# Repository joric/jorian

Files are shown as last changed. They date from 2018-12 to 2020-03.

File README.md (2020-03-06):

# Jorian

44-key 16-column wireless split keyboard in a 100x100 mm PCB

## Disclaimer

The keyboard layout is derived from [Jian layout](http://www.keyboard-layout-editor.com/#/gists/4b6c2af67148f58ddd6c6b2976c4370f) (just visually, there was no actual copying involved).
There are multiple [issues](https://github.com/joric/jorian/wiki/Issues) in my version.
Please buy Jian from its author, [/u/KgOfHedgehogs](http://reddit.com/u/KgOfHedgehogs), he's running a high quality commercial batch.

## Download

You can download Gerber files and schematic in the [releases section](https://github.com/joric/jorian/releases).

## Instructions

Please refer to the public [Jorian wiki](https://github.com/joric/jorian/wiki).

## Pictures

### Version 1.0

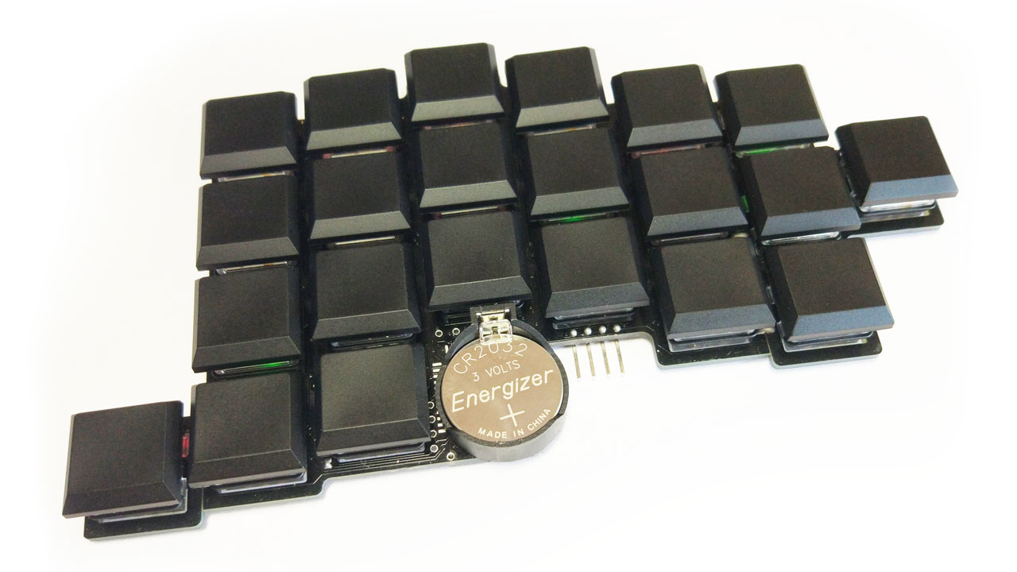
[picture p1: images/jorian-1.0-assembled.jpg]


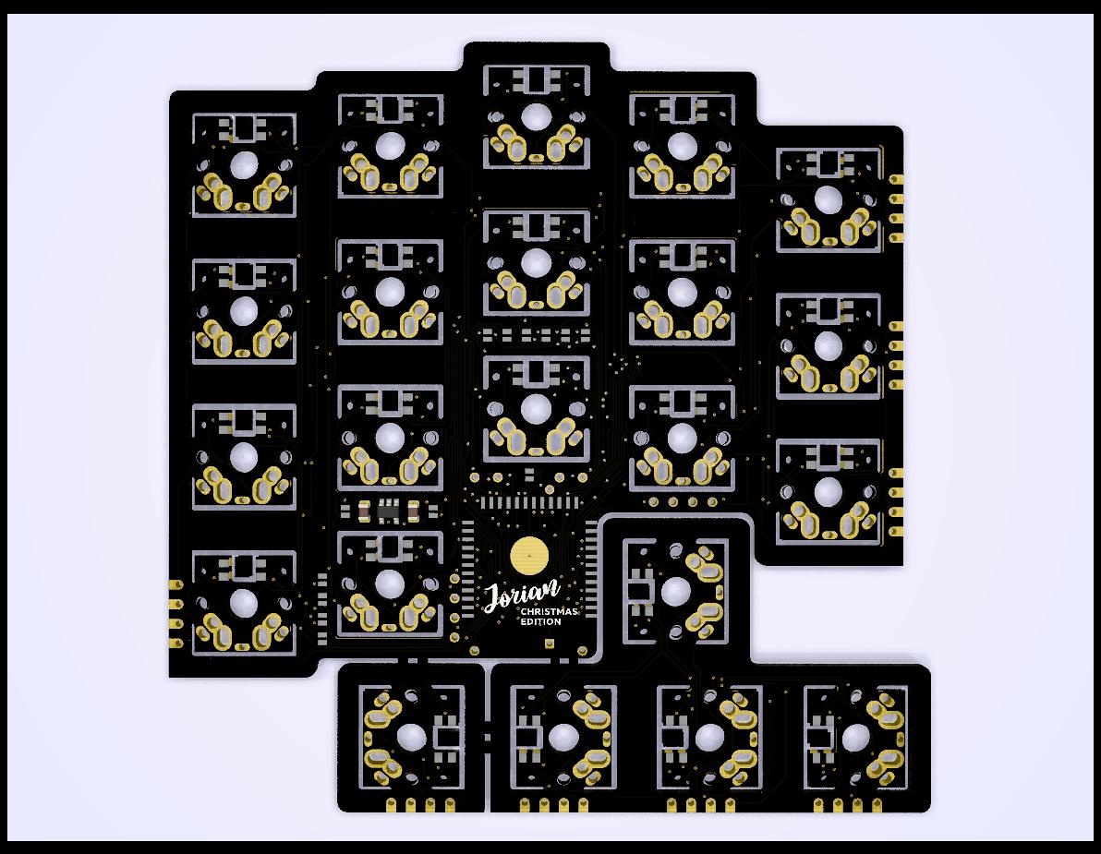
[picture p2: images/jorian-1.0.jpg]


## References

* Reddit thread: https://www.reddit.com/r/MechanicalKeyboards/comments/aj0mos/jorian_christmas_edition
* My nRF5x QMK fork: https://github.com/joric/qmk_firmware/commits/nrf52

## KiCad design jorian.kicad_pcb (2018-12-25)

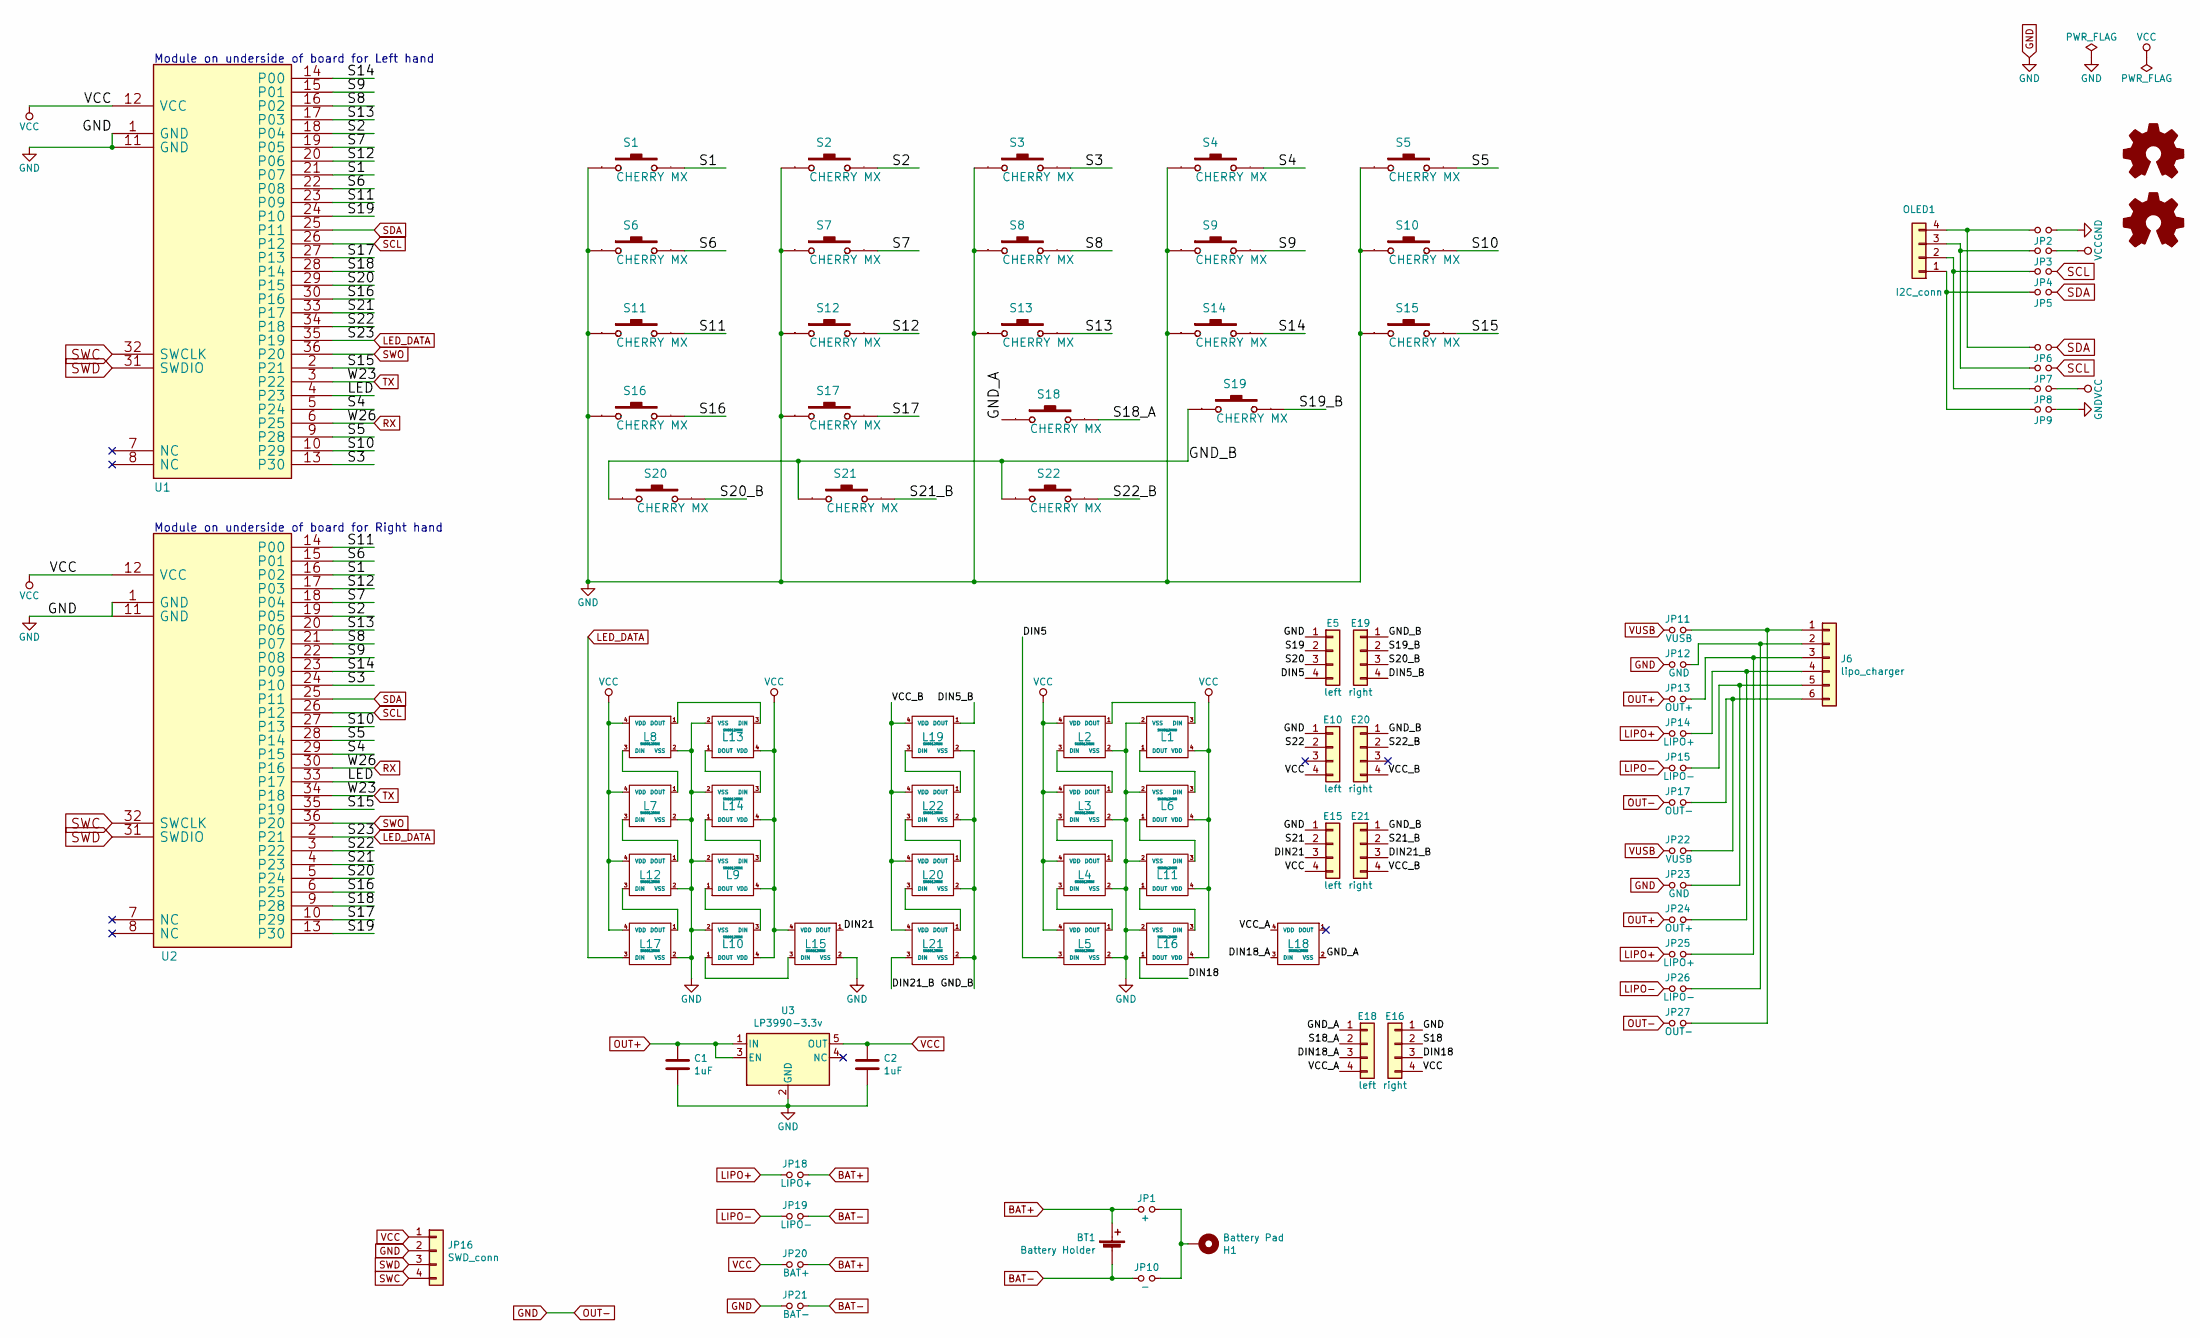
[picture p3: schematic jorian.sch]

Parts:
BT1: Battery Holder; cr2032_bs-7
C1, C2: 1uF; C_0805
E5, E10, E15, E18: left; edge_conn
E16, E19, E20, E21: right; edge_conn
G1, G2: Logo_Open_Hardware_Small; jorian_logo
H1: Battery Pad; battery_pad
J6: lipo_charger; lipo_charger_03962A
JP1: +; jumper
JP2, JP3, JP4, JP5, JP6, JP7, JP8, JP9: jumper
JP10: -; jumper
JP11, JP22: VUSB; jumper
JP12, JP23: GND; jumper
JP13, JP24: OUT+; jumper
JP14, JP18, JP25: LIPO+; jumper
JP15, JP19, JP26: LIPO-; jumper
JP16: SWD_conn; connector_swd
JP17, JP27: OUT-; jumper
JP20: BAT+; jumper
JP21: BAT-; jumper
L1, L2, L3, L4, L5, L6, L7, L8, L9, L10, L11, L12, L13, L14, L15, L16, L17, L18, L19, L20, L21, L22: SK6812MINI; kbd_SK6812MINI
OLED1: I2C_conn; connector_i2c
S1, S2, S3, S4, S5, S6, S7, S8, S9, S10, S11, S12, S13, S14, S15, S16, S17, S18, S19, S20, S21, S22: CHERRY MX; cherry
U1, U2: nrf51822_smd
U3: LP3990-3.3v; SOT-23-5

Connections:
/DIN5: E5.4, L5.3 (DIN)
/DIN5_B: E19.4, L19.1 (DOUT)
/DIN18: E16.3, L16.1 (DOUT)
/DIN18_A: E18.3, L18.3 (DIN)
/DIN21: E15.3, L15.1 (DOUT)
/DIN21_B: E21.3, L21.3 (DIN)
/GND_A: E18.1, L18.2 (VSS), S18.1
/GND_B: E19.1, E20.1, E21.1, L19.2 (VSS), L20.2 (VSS), L21.2 (VSS), L22.2 (VSS), S19.1, S20.1, S21.1, S22.1
/LED: U1.4 (P23), U2.33 (P17)
/S1: S1.2, U1.21 (P07), U2.16 (P02)
/S2: S2.2, U1.18 (P04), U2.19 (P05)
/S3: S3.2, U1.13 (P30), U2.24 (P10)
/S4: S4.2, U1.5 (P24), U2.29 (P15)
/S5: S5.2, U1.9 (P28), U2.28 (P14)
/S6: S6.2, U1.22 (P08), U2.15 (P01)
/S7: S7.2, U1.19 (P05), U2.18 (P04)
/S8: S8.2, U1.16 (P02), U2.21 (P07)
/S9: S9.2, U1.15 (P01), U2.22 (P08)
/S10: S10.2, U1.10 (P29), U2.27 (P13)
/S11: S11.2, U1.23 (P09), U2.14 (P00)
/S12: S12.2, U1.20 (P06), U2.17 (P03)
/S13: S13.2, U1.17 (P03), U2.20 (P06)
/S14: S14.2, U1.14 (P00), U2.23 (P09)
/S15: S15.2, U1.2 (P21), U2.35 (P19)
/S16: S16.2, U1.30 (P16), U2.6 (P25)
/S17: S17.2, U1.27 (P13), U2.10 (P29)
/S18: E16.2, U1.28 (P14), U2.9 (P28)
/S18_A: E18.2, S18.2
/S19: E5.2, U1.24 (P10), U2.13 (P30)
/S19_B: E19.2, S19.2
/S20: E5.3, U1.29 (P15), U2.5 (P24)
/S20_B: E19.3, S20.2
/S21: E15.2, U1.33 (P17), U2.4 (P23)
/S21_B: E21.2, S21.2
/S22: E10.2, U1.34 (P18), U2.3 (P22)
/S22_B: E20.2, S22.2
/VCC_A: E18.4, L18.4 (VDD)
/VCC_B: E20.4, E21.4, L19.4 (VDD), L20.4 (VDD), L21.4 (VDD), L22.4 (VDD)
BAT+: BT1.1 (+), JP1.2, JP18.2, JP20.2
BAT-: BT1.2 (-), JP10.2, JP19.2, JP21.2
GND: C1.2, C2.2, E5.1, E10.1, E15.1, E16.1, JP2.1, JP9.1, JP12.1, JP16.2, JP17.1, JP21.1, JP23.1, JP27.1, L1.2 (VSS), L2.2 (VSS), L3.2 (VSS), L4.2 (VSS), L5.2 (VSS), L6.2 (VSS), L7.2 (VSS), L8.2 (VSS), L9.2 (VSS), L10.2 (VSS), L11.2 (VSS), L12.2 (VSS), L13.2 (VSS), L14.2 (VSS), L15.2 (VSS), L16.2 (VSS), L17.2 (VSS), S1.1, S2.1, S3.1, S4.1, S5.1, S6.1, S7.1, S8.1, S9.1, S10.1, S11.1, S12.1, S13.1, S14.1, S15.1, S16.1, S17.1, U1.1 (GND), U1.11 (GND), U2.1 (GND), U2.11 (GND), U3.2 (GND)
LED_DATA: L17.3 (DIN), U1.35 (P19), U2.2 (P21)
LIPO+: JP14.1, JP18.1, JP25.1
LIPO-: JP15.1, JP19.1, JP26.1
unnamed: H1.1, JP1.1, JP10.1
unnamed: J6.1, JP11.2, JP27.2
unnamed: J6.2, JP12.2, JP26.2
unnamed: J6.3, JP13.2, JP25.2
unnamed: J6.4, JP14.2, JP24.2
unnamed: J6.5, JP15.2, JP23.2
unnamed: J6.6, JP17.2, JP22.2
unnamed: JP2.2, JP6.2, OLED1.4
unnamed: JP3.2, JP7.2, OLED1.3
unnamed: JP4.2, JP8.2, OLED1.2
unnamed: JP5.2, JP9.2, OLED1.1
unnamed: L1.1 (DOUT), L6.3 (DIN)
unnamed: L1.3 (DIN), L2.1 (DOUT)
unnamed: L2.3 (DIN), L3.1 (DOUT)
unnamed: L3.3 (DIN), L4.1 (DOUT)
unnamed: L4.3 (DIN), L5.1 (DOUT)
unnamed: L7.1 (DOUT), L8.3 (DIN)
unnamed: L10.1 (DOUT), L15.3 (DIN)
unnamed: L9.1 (DOUT), L10.3 (DIN)
unnamed: L11.1 (DOUT), L16.3 (DIN)
unnamed: L6.1 (DOUT), L11.3 (DIN)
unnamed: L7.3 (DIN), L12.1 (DOUT)
unnamed: L12.3 (DIN), L17.1 (DOUT)
unnamed: L13.1 (DOUT), L14.3 (DIN)
unnamed: L8.1 (DOUT), L13.3 (DIN)
unnamed: L9.3 (DIN), L14.1 (DOUT)
unnamed: L19.3 (DIN), L22.1 (DOUT)
unnamed: L20.1 (DOUT), L22.3 (DIN)
unnamed: L20.3 (DIN), L21.1 (DOUT)
OUT+: C1.1, JP13.1, JP24.1, U3.1 (IN), U3.3 (EN)
RX: U1.6 (P25), U2.30 (P16)
SCL: JP4.1, JP7.1, U1.26 (P12), U2.26 (P12)
SDA: JP5.1, JP6.1, U1.25 (P11), U2.25 (P11)
SWC: JP16.4, U1.32 (SWCLK), U2.32 (SWCLK)
SWD: JP16.3, U1.31 (SWDIO), U2.31 (SWDIO)
SWO: U1.36 (P20), U2.36 (P20)
TX: U1.3 (P22), U2.34 (P18)
VCC: C2.1, E10.4, E15.4, E16.4, JP3.1, JP8.1, JP16.1, JP20.1, L1.4 (VDD), L2.4 (VDD), L3.4 (VDD), L4.4 (VDD), L5.4 (VDD), L6.4 (VDD), L7.4 (VDD), L8.4 (VDD), L9.4 (VDD), L10.4 (VDD), L11.4 (VDD), L12.4 (VDD), L13.4 (VDD), L14.4 (VDD), L15.4 (VDD), L16.4 (VDD), L17.4 (VDD), U1.12 (VCC), U2.12 (VCC), U3.5 (OUT)
VUSB: JP11.1, JP22.1

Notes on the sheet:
Module on underside of board for Right hand
Module on underside of board for Left hand

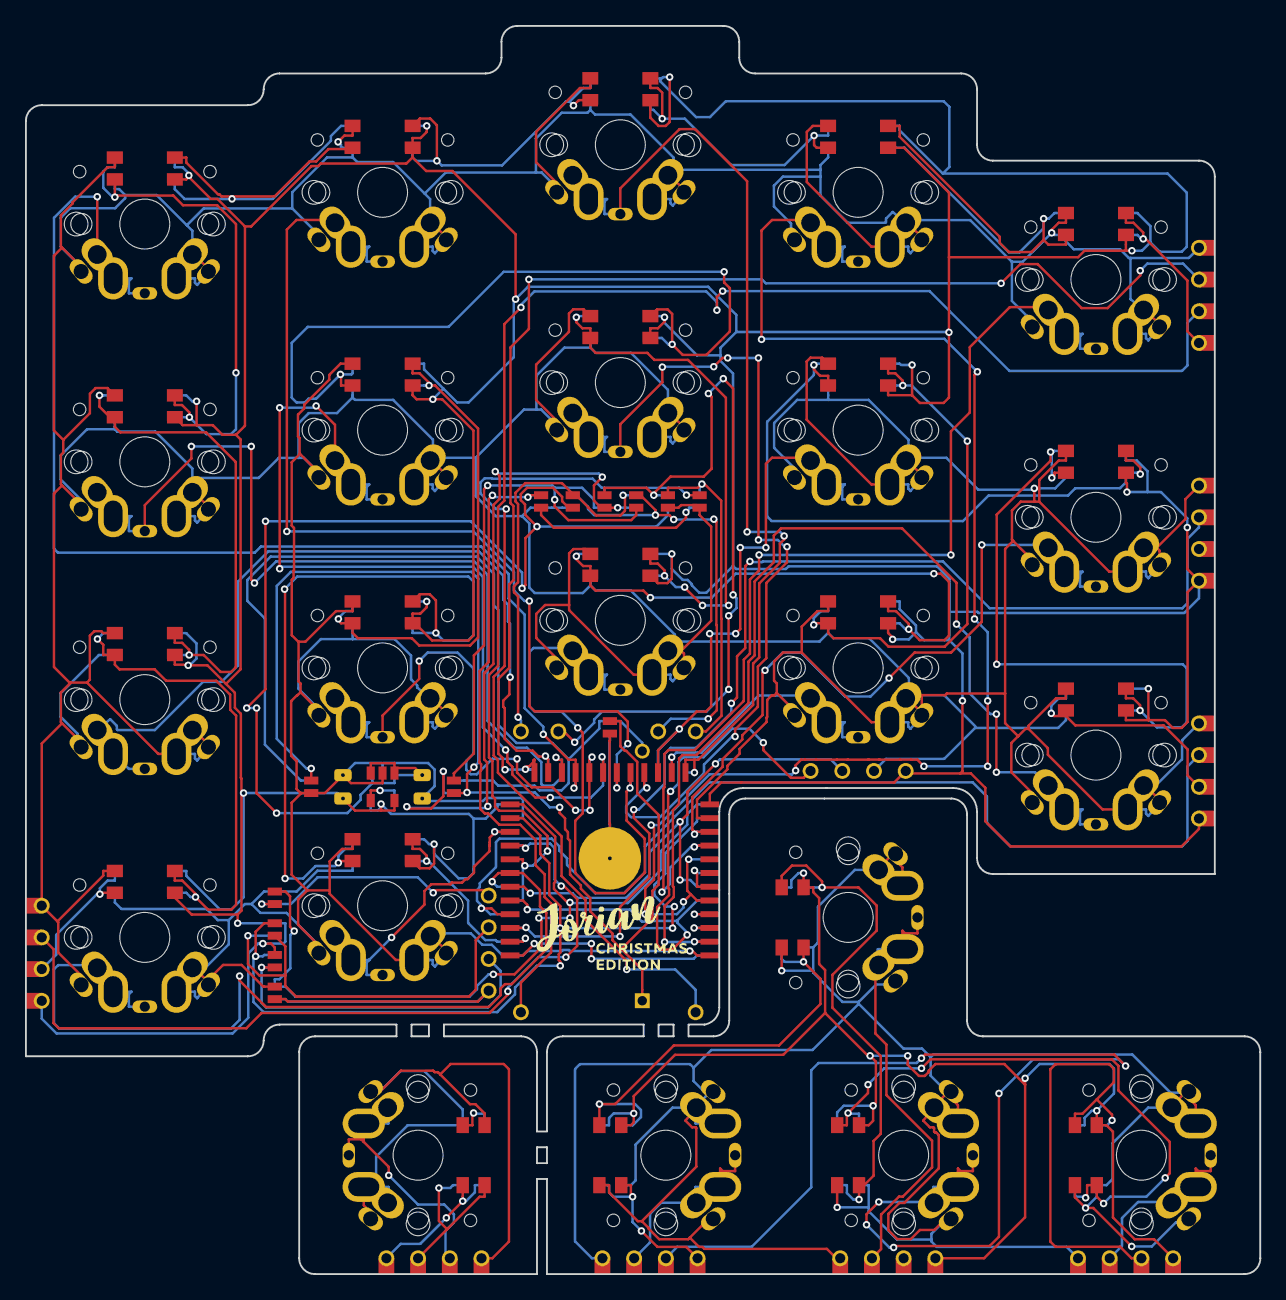
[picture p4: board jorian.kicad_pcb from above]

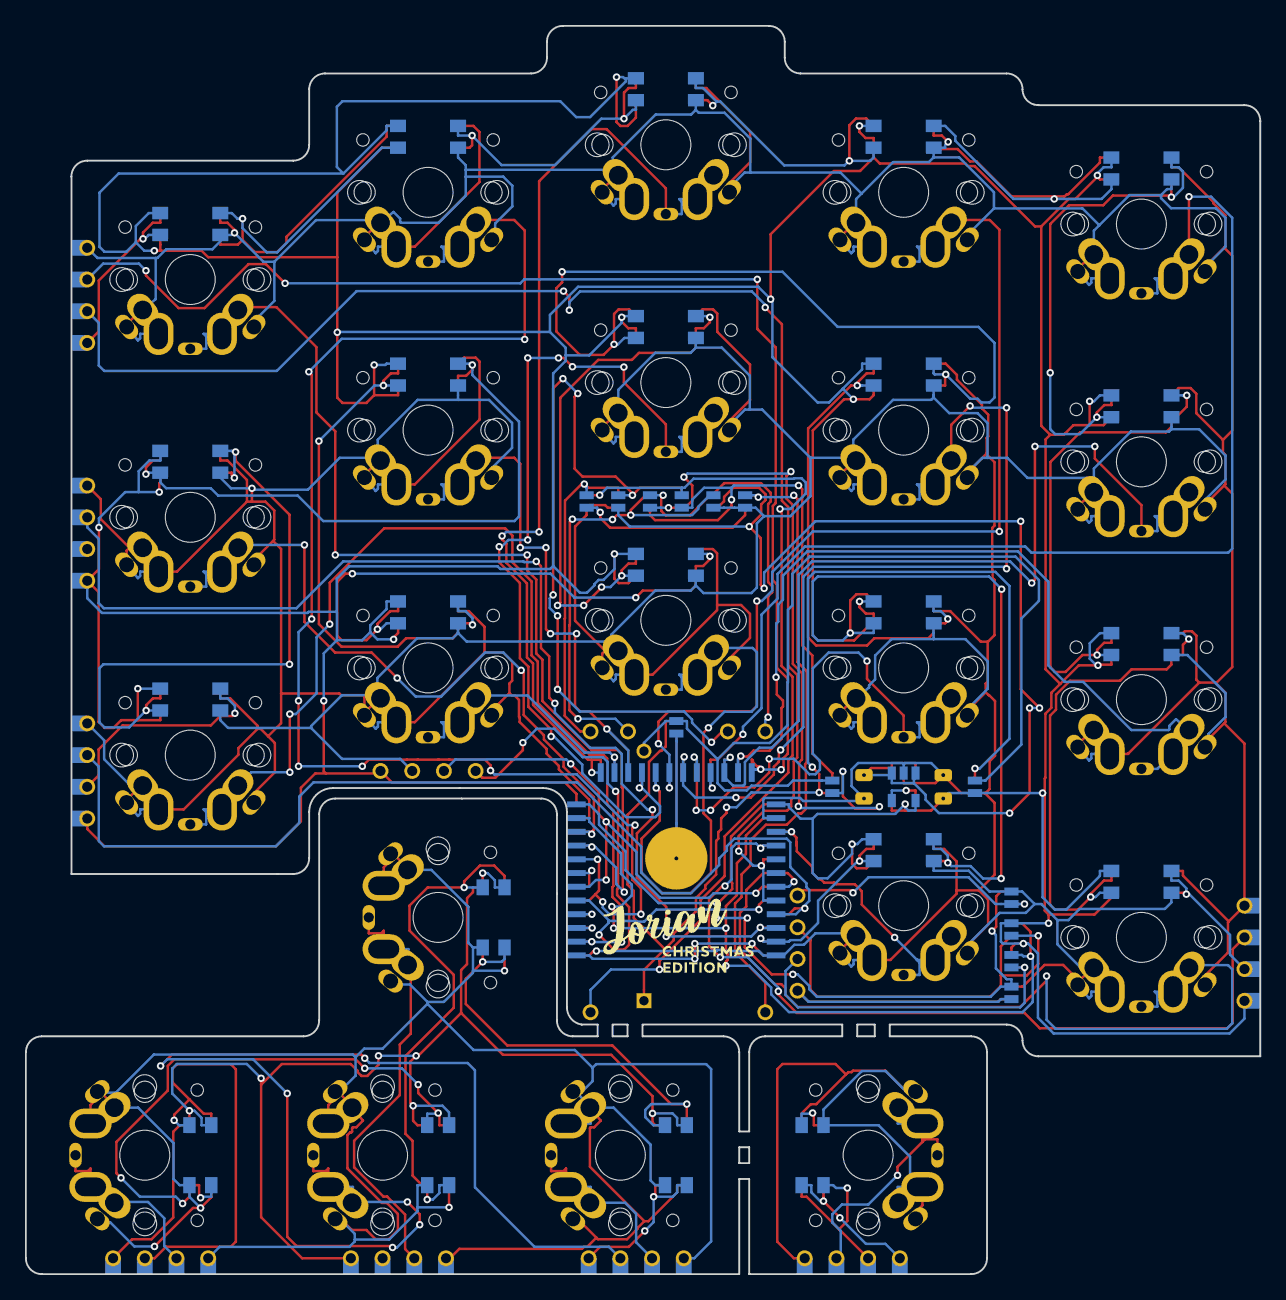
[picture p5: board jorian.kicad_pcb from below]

Board: 2 copper layers, 98.9 x 100.0 mm, 90 parts (20 on the bottom side), 83 nets.

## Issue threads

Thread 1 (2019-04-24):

[Help] Issues getting Jorian to work

geoah, 2019-04-24:
Hey there; first of all thank you for open sourcing this design, the design is just amazing and the fact it's a 100x100 makes it even more awesome!

---

I've printed the 1.0 release PCBs and simply soldered some YJ-14015s and some switched on them.
For now I've skipped all solder jumpers and I'm powering the boards through the SWD connector.

I've tried flashing these three with both an stlink:
* your pre-compiled bluetosis firmware from your releases
* the bluetosis firmware from your `jorian` branch
* the qmk firmware from your `nrf5x` branch

also I'm always flashing `s130_nrf51_2.0.1_softdevice` just for good measure.

___But I'm always having the same issue:___
When I first flash the keyboard, I can see the device broadcasting the correct name, I try to connect to it, it shows as connected, and within a couple of seconds it disconnects and never shows up again.

The only way to get it to show up again is re-flashing it or resetting it.
After that, same thing happens. Shows up. Connects. Dies.

__Is there something very obvious I'm missing? Have I completely forgotten to do something?__

---

ps. I've converted my blue pill into a black magic, and I'm trying to use it to debug the board, but nothing seems to show up. (I'll keep trying to get debugging to work for now)

pps. I do apologise if this is the wrong place to ask for this king of help/support, and I wanted to thank you again for all the hard work you've done with joria, bluetosis, and now the nrf fork of qmk and nrfmicro.

ppps.
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

Thank you very much in advance.

joric, 2019-04-24:
Nordic chip pairing is a bit weird. You need to reset all bonds first (see keyboard shortcuts) then should pair and connect just fine. I'm currently working on nRF5x branch, and you just gave me a boost (also I have a few keyboards just laying around without a properly working firmware, figures 10 PCBs is a lot :)
You can try mitosis firmware and mitosis receiver for now, it should work fine: https://github.com/joric/qmk_firmware/tree/mitosis-jorian/keyboards/mitosis/keymaps/jorian

dejanr, 2019-04-24:
@joric impressive work with BLE! I am owning one Atreus so far, and was looking for BLE keyboard. And your layout looks impressive.

Where you got those tin profile keys and key caps?

Keep up the great work, looking forward into making one for myself!

joric, 2019-04-24:
@dejanr well thankyou! it's [Jian](https://redd.it/apfxsj) layout actually. Those switches are Kailh LP, keycaps are from here I guess ($14, free shipping) https://www.aliexpress.com/item//32915900901.html I don't like low profile keys, as figures, they're really uncomfortable in the thumb area.

joric, 2019-09-03:
@geoah this project now has a new rgb firmware and public wiki https://github.com/joric/jorian/wiki

Closed 2019-11-20.

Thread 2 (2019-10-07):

nRF52840 usb dongle as receiver?

pashky, 2019-10-07:
Hi

Just dived into rabbit hole of wireless split boards and now of course I want one. I’ve been using wired ergodash clone for some time and I like it, but your design looks particularly appealing because of Ъ and creative use of 100x100mm :)

I have a question though. Now that nRF52 branch of QMK exists, is there anything that would not let me use this thing as receiver? Any thoughts?

https://www.digikey.co.uk/product-detail/en/nordic-semiconductor-asa/NRF52840-DONGLE/1490-1073-ND/9491124

joric, 2019-10-07:
You can try. I just used nrf51 soldered to the 3.3v pro micro. https://github.com/reversebias/mitosis/pull/10

pashky, 2019-10-07:
Thanks. Didn’t notice that issues page before. Nrf51 is still cheaper and I don’t  plan to install LEDs anyway, so as long as it works I figured I’d give it a go.

I’m interested in your opinion though, what would you use if you’re to build something similar today?

joric, 2019-10-07:
I have a few modules used here https://github.com/joric/nrfmicro/ I'd probaly use them but I don't know I'd rather use pro-micro sized modules than dead-soldered ones. There's a closed-source keyboard like this already (runs native QMK for arm) https://github.com/sekigon-gonnoc/SISO59-doc/blob/master/README.md

Closed 2019-10-07.

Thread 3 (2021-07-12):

Question: Kit, BOM, or more info?

MikaelElkiaer, 2021-07-12:
Heya, I really like this board, but I am having some troubles figuring out exactly what is needed. Is there a kit to be found anywhere? Or a detailed BOM?

Also, I'd like to omit the pinky and extra thumb bits, is that straightforward, or will it ef up some connections?

joric, 2021-07-12:
There's no much sense in this board anymore, 100x100 boards don't cost $2 and JLCPCB would ask extra for the number of slots and it has multiple flaws such as RGB leak, etc. There's everything in the wiki. Extra bits are mandatory. I don't really remember the layout but the thumb bit lets data out and the thumb bits are all interconnected also.

MikaelElkiaer, 2021-07-12:
Oh, thanks for clearing that up. Shifting my gaze to Ferris then.

Closed 2021-07-12.

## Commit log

2018-12-18 second commit
    [jorian.kicad_pcb, jorian.sch]
2018-12-19 added charger
    [jorian.kicad_pcb, jorian.sch]
2018-12-19 autorouted charger take 1
    [jorian.kicad_pcb, jorian.sch]
2018-12-20 autorouted charger take 2
    [jorian.kicad_pcb, jorian.sch]
2018-12-20 autorouted version with better usb-c
    [jorian.sch]
2018-12-21 autorouted charger, alpha version
    [jorian.kicad_pcb, jorian.sch]
2018-12-21 autorouted alpha, better placement
    [jorian.kicad_pcb, jorian.sch]
2018-12-21 updated placement
    [jorian.kicad_pcb]
2018-12-24 separate charger
    [jorian.kicad_pcb, jorian.sch]
2018-12-24 separate charger all
2018-12-24 sent files
    [jorian.kicad_pcb, jorian.sch]
2018-12-24 charger with holes, autorouted
    [jorian.kicad_pcb, jorian.sch]
2018-12-24 updated layout
    [jorian.kicad_pcb, jorian.sch]
2018-12-25 edge cuts 0.2 tolerance 0.175
    [jorian.kicad_pcb, jorian.sch]
2018-12-25 reroute take 3, moved a bit by hand
    [jorian.kicad_pcb]
2019-04-16 added more PCB issues
